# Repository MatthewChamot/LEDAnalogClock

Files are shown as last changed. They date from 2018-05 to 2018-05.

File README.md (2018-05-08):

# LEDAnalogClock
Project by Matthew Chamot

Code and CAD files for an analog LED clock.  

Sometimes in the middle of the night, it is hard to easily see the time.  This clock acts as a night light and is also easy to read, even if your eyes are still a little sleepy.  The angle of the clock hand shows the hours and the number of lit LEDs shows the minutes.   In the image below, the time is 10:45.

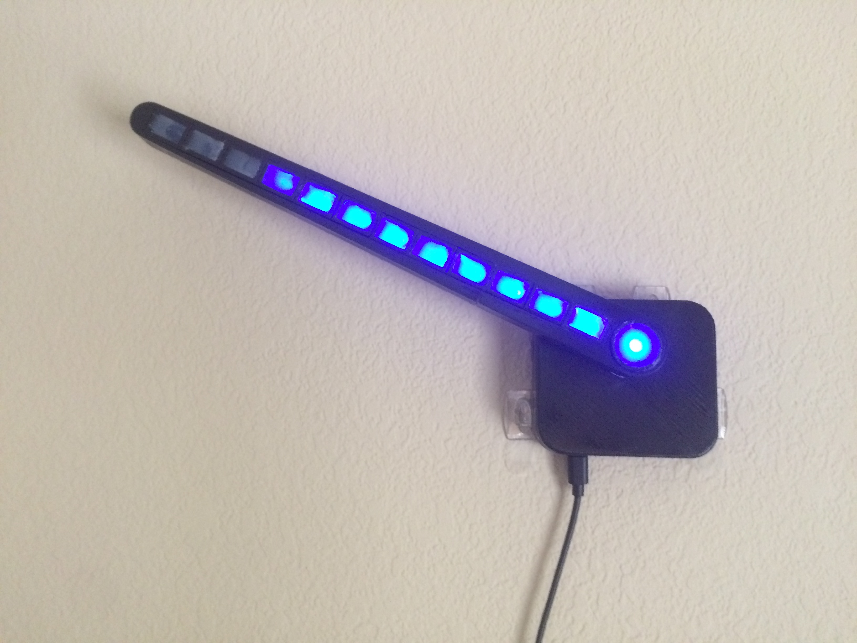
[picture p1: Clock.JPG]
clock image


#### Description
  The housing for the clock was custom designed and 3d printed to nicely enclose the electronics.  The microprocessor used was a Teensy 3.2 with the crystal attached for time accuracy.  The minutes are displayed by the number of LEDs lit along the arm.  One LED for every 5 minutes.  On every hour, the servo rotates the hand to the correct position and after 24 hours the servo rotates the hand in reverse for two full revolutions so that the wires inside do not get too twisted.  A unique worm gear design prevents the weight of the arm from back-driving the servo and allows the servo to be off until it is needed every hour.

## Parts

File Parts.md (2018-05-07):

## Parts Used

| Part | Quantity | Source |
| --- | :---: | --- |
| Diffused LED - Blue 10mm | 13 | https://www.sparkfun.com/products/10635  |
| Teensy 3.2 | 1 | https://www.sparkfun.com/products/13736  |
| Crystal 32kHz | 1 | https://www.sparkfun.com/products/540 |
| Rotary Encoder | 1 | https://www.sparkfun.com/products/9117 |
| Continous Rotation Micro Servo | 1 | https://www.sparkfun.com/products/10189  |
| Ribbon Cable - 6 wire | 1 | https://www.sparkfun.com/products/10646  |

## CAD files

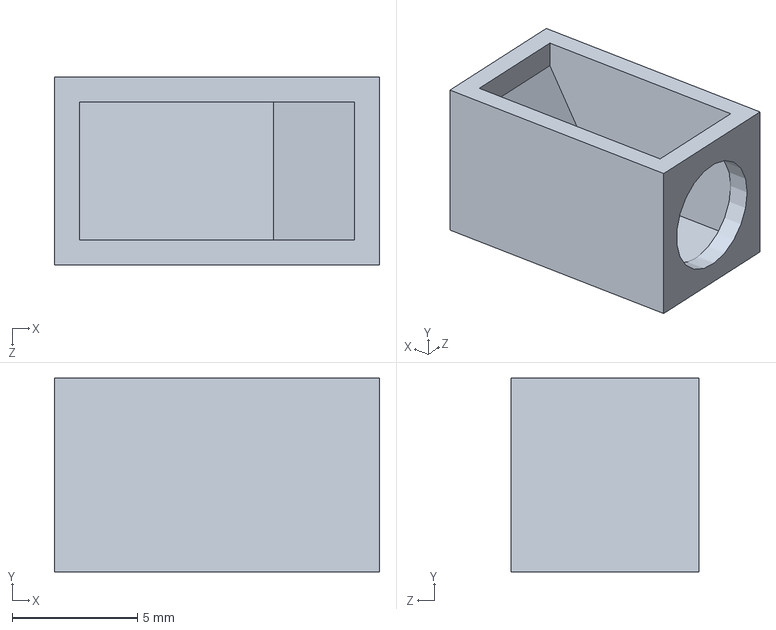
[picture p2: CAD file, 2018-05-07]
Clock CAD/Light_Test2.SLDPRT
13.0 x 7.75 x 7.50 mm

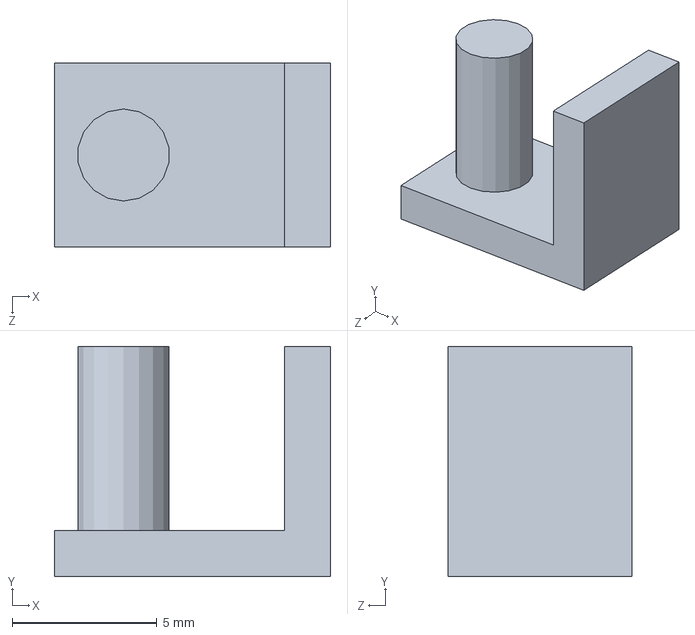
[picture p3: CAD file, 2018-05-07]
Clock CAD/Clip.SLDPRT
9.53 x 7.94 x 6.35 mm

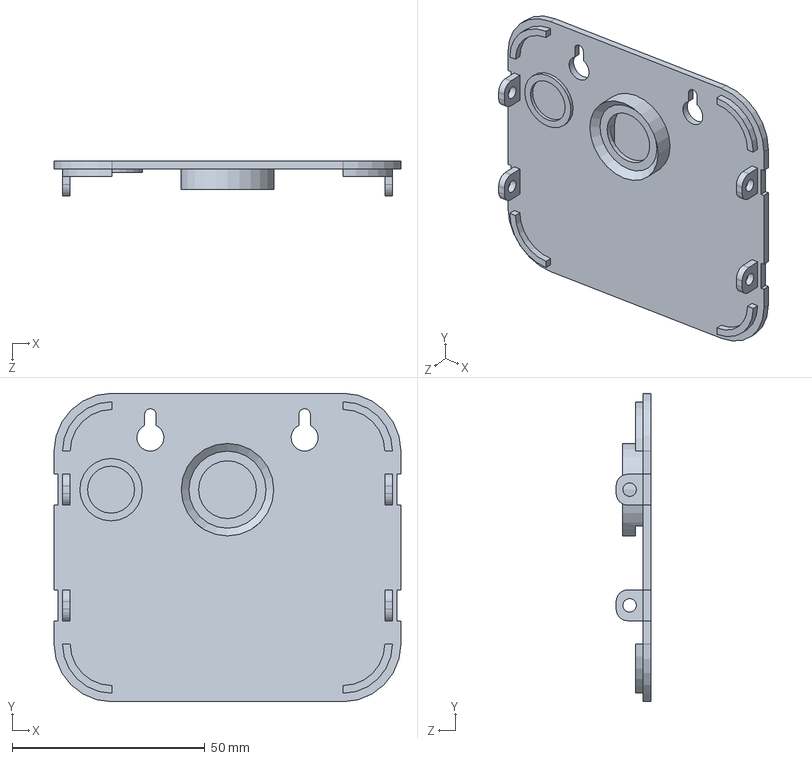
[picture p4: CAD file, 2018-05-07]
Clock CAD/Back.SLDPRT
90.0 x 80.0 x 9.00 mm

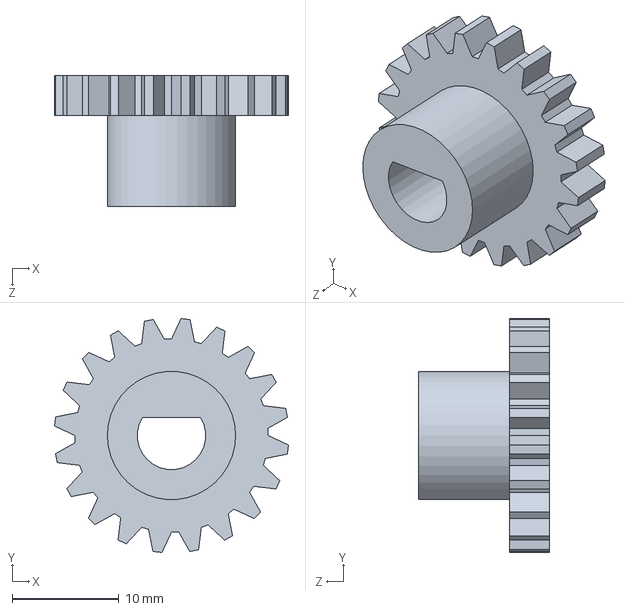
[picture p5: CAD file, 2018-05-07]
Clock CAD/20TGear.SLDPRT
21.9 x 21.9 x 12.2 mm

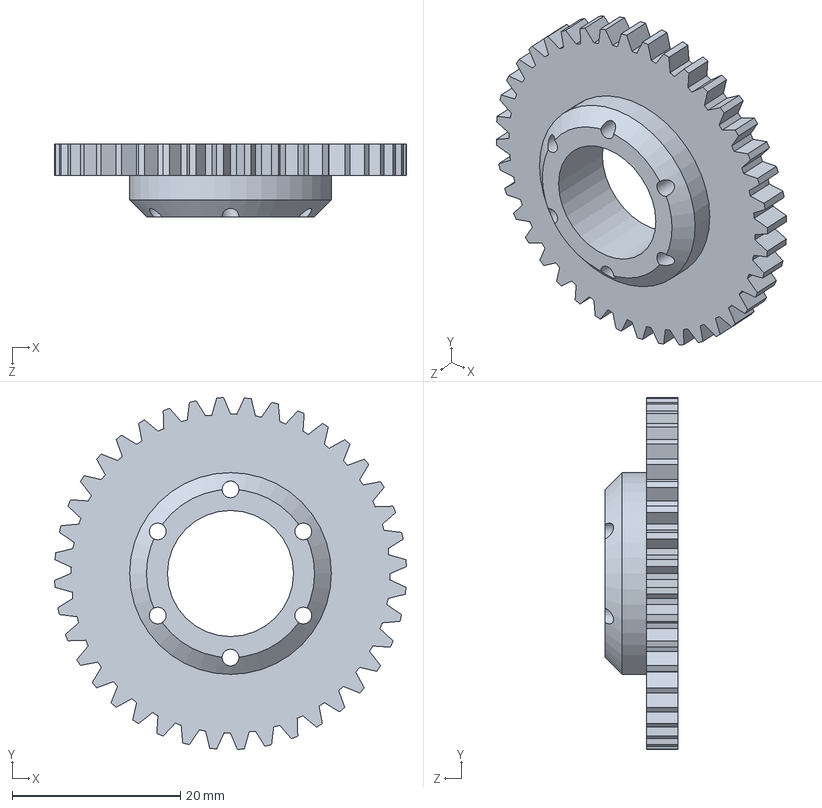
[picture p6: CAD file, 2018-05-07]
Clock CAD/40TGear.SLDPRT
41.9 x 41.9 x 8.65 mm

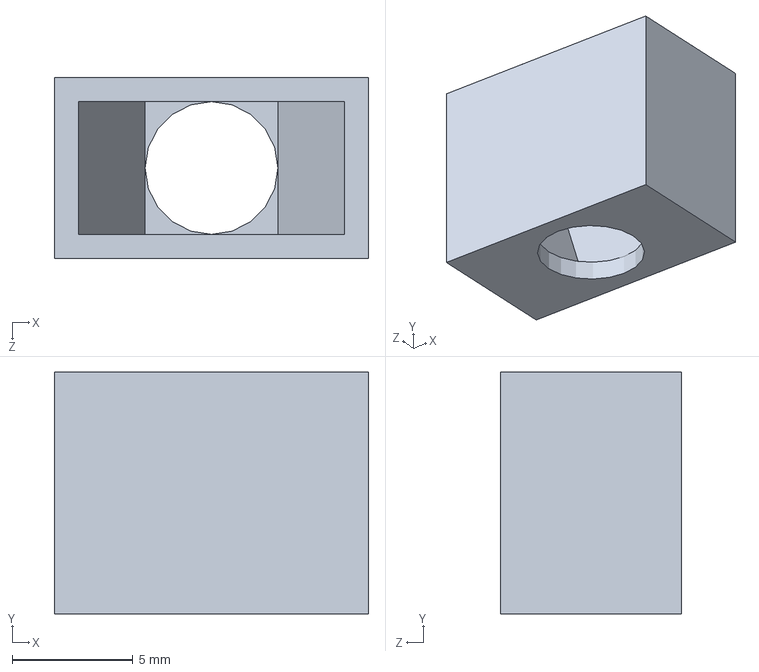
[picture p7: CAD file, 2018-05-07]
Clock CAD/Light_Test.SLDPRT
13.0 x 10.0 x 7.50 mm

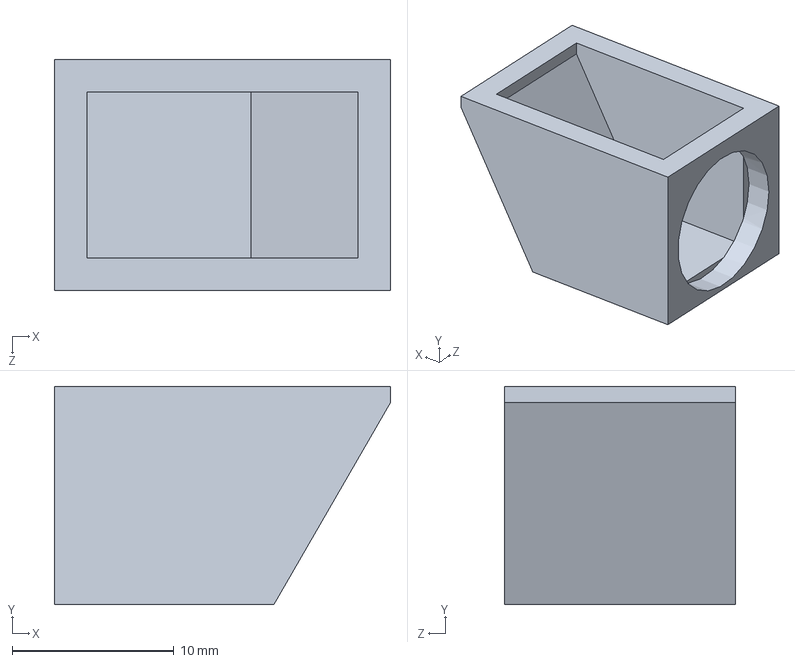
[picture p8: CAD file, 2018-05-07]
Clock CAD/Hand.SLDPRT
20.8 x 13.5 x 14.3 mm

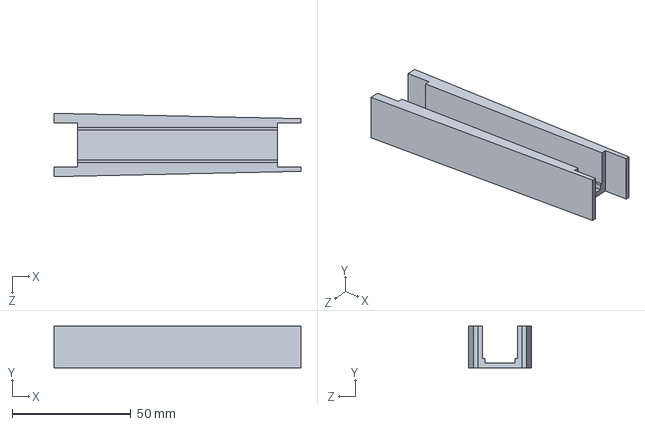
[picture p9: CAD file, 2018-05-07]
Clock CAD/Arm2.SLDPRT
103.8 x 17.5 x 26.6 mm

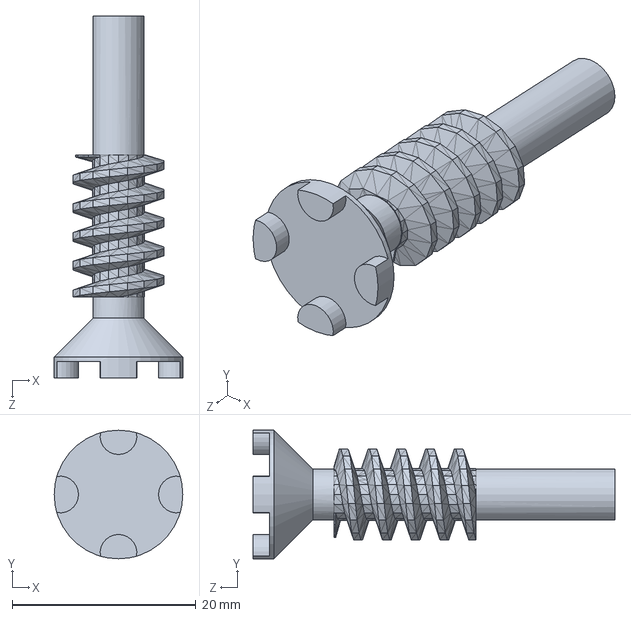
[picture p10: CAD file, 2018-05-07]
Clock CAD/WormGear.SLDPRT
14.0 x 14.0 x 39.4 mm

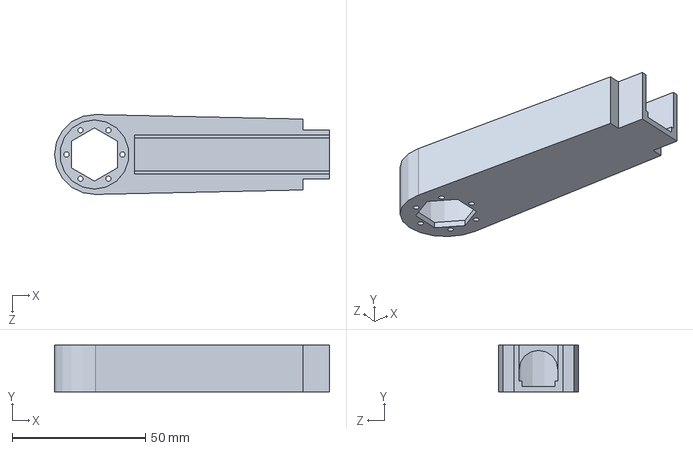
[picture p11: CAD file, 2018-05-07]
Clock CAD/Arm.SLDPRT
103.3 x 17.5 x 30.0 mm

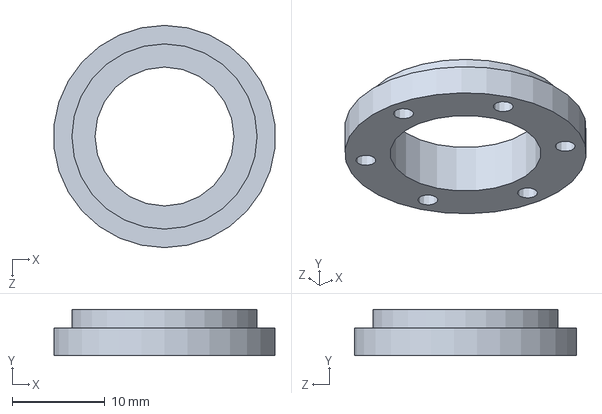
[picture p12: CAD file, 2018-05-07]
Clock CAD/GearHolder.SLDPRT
23.9 x 5.00 x 24.0 mm

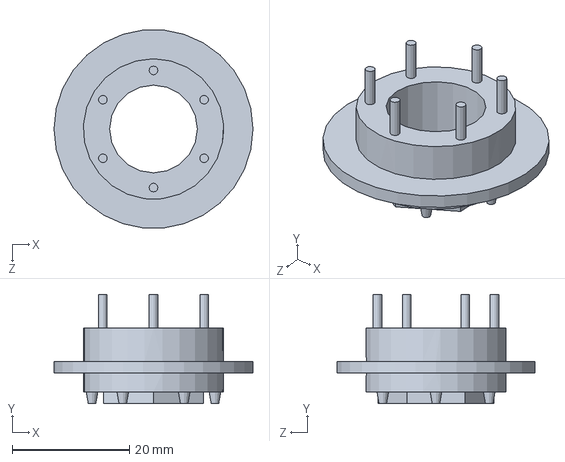
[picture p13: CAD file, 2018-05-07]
Clock CAD/Hub.SLDPRT
34.0 x 18.6 x 33.8 mm

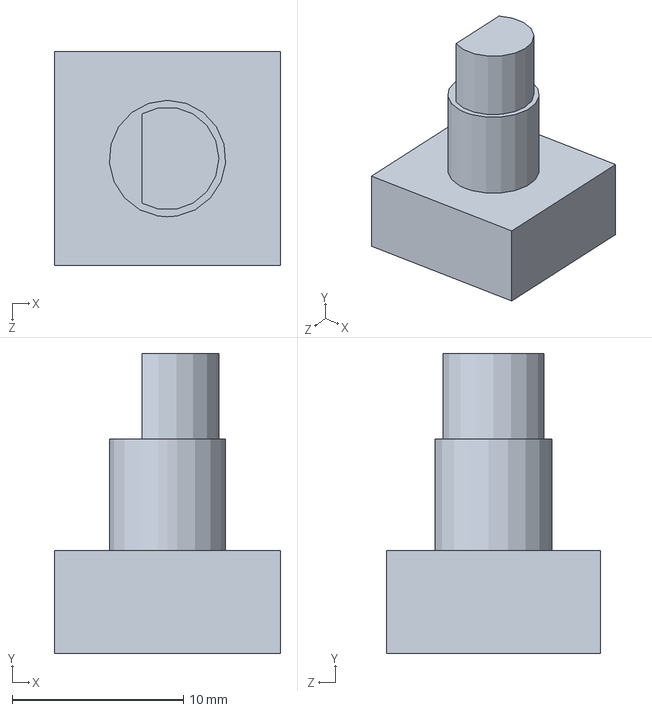
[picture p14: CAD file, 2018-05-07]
Clock CAD/Encoder.SLDPRT
13.2 x 17.5 x 12.5 mm

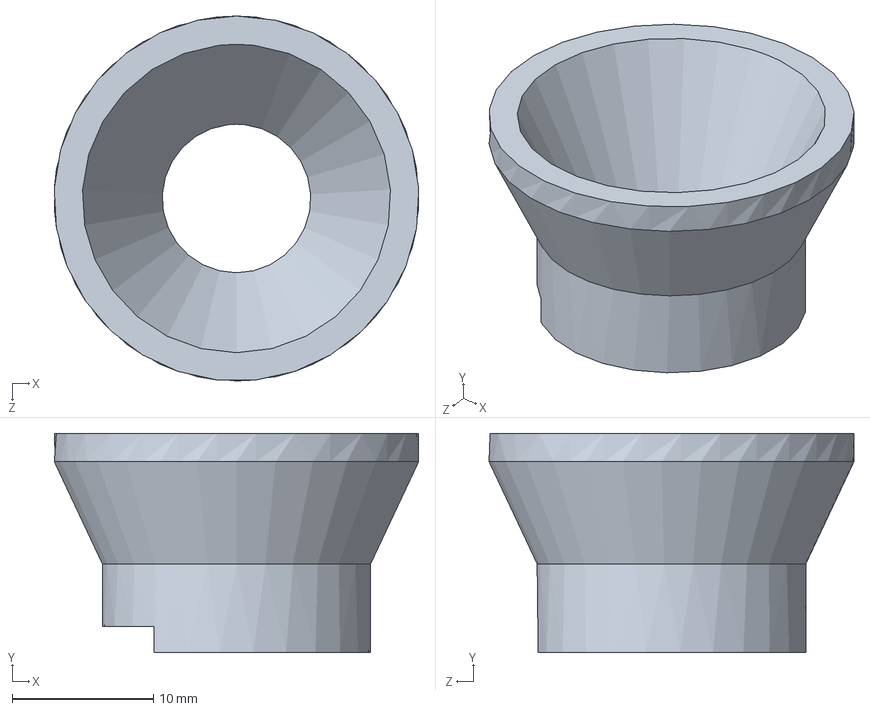
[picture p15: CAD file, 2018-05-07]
Clock CAD/Center Light.SLDPRT
25.8 x 15.5 x 25.8 mm

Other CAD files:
Clock CAD/LED.SLDPRT
Clock CAD/Peg.SLDPRT
Clock CAD/Light.SLDPRT
Clock CAD/20TGear.STL
Clock CAD/40TGear.STL
Clock CAD/Arm.STL
Clock CAD/Arm2.STL
Clock CAD/Arm3.SLDPRT
Clock CAD/Arm3.STL
Clock CAD/Back.STL
Clock CAD/Body.SLDPRT
Clock CAD/Body.STL
Clock CAD/Center Light.STL
Clock CAD/Clip.STL
Clock CAD/Hand.STL
Clock CAD/Hub.STL
Clock CAD/Light_Test.STL
Clock CAD/Light_Test2.STL
Clock CAD/Micro Servo.SLDPRT
Clock CAD/Peg.STL
Clock CAD/QuadHorn.SLDPRT
Clock CAD/Teensy32.SLDPRT
Clock CAD/Test.STL
Clock CAD/Washer.SLDPRT
Clock CAD/Washer.STL
Clock CAD/WormGear.STL

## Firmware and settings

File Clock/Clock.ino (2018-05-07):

//  Clock Code  
//  Created by Matthew Chamot 
//  March 2018

// Encoder Variables
#define ENC_A 7
#define ENC_B 8
#define CW 0
#define CCW 180
#define STOP 89
volatile byte state = 0;
volatile byte count = 0;
volatile byte dir = CCW;  // direction
volatile byte ledcount = 0;

// Variable keep track of state and timing
bool reset_mode = true;
bool button_pushed = false;
bool setting_time = false;
int pos = 0;
unsigned long hold_time = 0;

// Timer for PWM for the center LED
IntervalTimer ledTimer;

// Servo Variables
#include <Servo.h>
Servo motor;

// Time Variables
#include <TimeLib.h>

// LED Variables
#define LEDC  12
#define LED1  9 //3
#define LED2  6 //4
#define LED3  4 //5
#define LED4  23 //6
#define LED5  20 //9
#define LED6  32 //10
#define LED7  10 //23
#define LED8  5 //22
#define LED9  3 //21
#define LED10 22 //20
#define LED11 21 //25
#define LED12 25 //32


void setup() {
  
  // Encoder
  pinMode(ENC_A, INPUT);
  digitalWrite(ENC_A, HIGH);
  pinMode(ENC_B, INPUT);
  digitalWrite(ENC_B, HIGH);
  attachInterrupt(digitalPinToInterrupt(ENC_A), A_ISR, CHANGE);
  attachInterrupt(digitalPinToInterrupt(ENC_B), B_ISR, CHANGE);
  Serial.begin (115200);
  Serial.println("Start");
  ledTimer.begin(centerPWM,1000);  // every .001 seconds 

  // Servo
  motor.attach(1);
  motor.write(STOP);

  // Time
  // set the Time library to use Teensy 3.0's RTC to keep time
  setSyncProvider(getTeensy3Time);

  // LED test on startup
  int LedTime = 100;
  pinMode(LED1, OUTPUT);
  pinMode(LED2, OUTPUT);
  pinMode(LED3, OUTPUT);
  pinMode(LED4, OUTPUT);
  pinMode(LED5, OUTPUT);
  pinMode(LED6, OUTPUT);
  pinMode(LED7, OUTPUT);
  pinMode(LED8, OUTPUT);
  pinMode(LED9, OUTPUT);
  pinMode(LED10, OUTPUT);
  pinMode(LED11, OUTPUT);
  pinMode(LED12, OUTPUT);
  pinMode(LEDC, OUTPUT);
  digitalWrite(LEDC, HIGH);
  delay(LedTime);
  analogWrite(LED1, 127);
  delay(LedTime);
  analogWrite(LED2, 127);
  delay(LedTime);
  analogWrite(LED3, 127);
  delay(LedTime);
  analogWrite(LED4, 127);
  delay(LedTime);
  analogWrite(LED5, 127);
  delay(LedTime);
  analogWrite(LED6, 127);
  delay(LedTime);
  analogWrite(LED7, 127);
  delay(LedTime);
  analogWrite(LED8, 127);
  delay(LedTime);
  analogWrite(LED9, 127);
  delay(LedTime);
  analogWrite(LED10, 127);
  delay(LedTime);
  analogWrite(LED11, 127);
  delay(LedTime);
  analogWrite(LED12, 127);
  delay(LedTime);
  analogWrite(LED12, 0);
  delay(LedTime);
  analogWrite(LED11, 0);
  delay(LedTime);
  analogWrite(LED10, 0);
  delay(LedTime);
  analogWrite(LED9, 0);
  delay(LedTime);
  analogWrite(LED8, 0);
  delay(LedTime);
  analogWrite(LED7, 0);
  delay(LedTime);
  analogWrite(LED6, 0);
  delay(LedTime);
  analogWrite(LED5, 0);
  delay(LedTime);
  analogWrite(LED4, 0);
  delay(LedTime);
  analogWrite(LED3, 0);
  delay(LedTime);
  analogWrite(LED2, 0);
  delay(LedTime);
  analogWrite(LED1, 0);
  
  // Button
  pinMode(14,INPUT_PULLUP);
  attachInterrupt(digitalPinToInterrupt(14), buttonpress, FALLING);

    
  // Reseting Mode
  while(reset_mode) {
    if(button_pushed == true) {
      delay(1000);
      if(digitalRead(14)==LOW) {
        reset_mode = false;
        Serial.println("Exiting Setup");
      }
      else {
        motor.write(CCW);
        Serial.println("Going Back");
      }
      button_pushed = false;
    }
    // Move back an half hour
    if(count<=255 && count>50) {
      motor.write(STOP);
      count = 0;
    }
  }

  // Initial Movement
  setting_time = true;
  pos = hour();
  if(pos < 12) {
    pos = pos + 12;
  }
  else {
    pos = pos - 12;
  }
  pos = pos*2;
  dir = CW;
  lightleds();
  motor.write(dir);

  while(setting_time) {
    if(count==pos) {
      motor.write(STOP);
      lightleds();
      setting_time = false;
    }
  }
  
}

void loop() {
    
  // Read the hour from the RTC and convert to encoder position
  pos = hour();
  if(pos < 12) {
    pos = pos + 12;
  }
  else {
    pos = pos - 12;
  }
  pos = pos*2;

  // Every 24 hours the clock fully reverses to prevent twisting of the LED wiring.
  if(count == 46 && pos == 0) {
    dir = CCW;
    motor.attach(1);
    motor.write(dir);
    setting_time  = true;
    while(setting_time) {
      if(count == 0) {
        motor.write(STOP);
        motor.detach();
        setting_time = false;
      }
      if(count > 200) {
        error();
      }
    }
    dir = CW;
    analogWrite(LED12, 0);
    analogWrite(LED11, 0);
    analogWrite(LED10, 0);
    analogWrite(LED9, 0);
    analogWrite(LED8, 0);
    analogWrite(LED7, 0);
    analogWrite(LED6, 0);
    analogWrite(LED5, 0);
    analogWrite(LED4, 0);
    analogWrite(LED3, 0);
    analogWrite(LED2, 0);
    analogWrite(LED1, 0);
  }

  // Every hour the clock hand moves 1/12 of a full circle
  if(count < pos) {
    motor.attach(1);
    motor.write(60);
    setting_time = true;
    while(setting_time) {
      if(count==pos) {
        motor.write(STOP);
        motor.detach();
        setting_time = false;
      }
    }  
  }
  
  // If the clock hand has rotated more than 2 revolutions, something is wrong
  if(count > 46) {
    error();
  }

  // Check the time every 10 seconds and light the LEDs to display minutes
  Serial.println(count);
  lightleds();
  delay(10000);

}



// ISR for encoder, switch A
// Encoder alternates ABAB for one direction and BABA for the other.
void A_ISR() {
  Serial.print("A ");
  if (dir == CW)
  {
    if (state == 1) state = 2;
    if (state == 3)
    {
      state = 0;
      count++;  
    }
  }

  else if (dir == CCW)
  {
    if (state == 0) state = 1;
    if (state == 2) state = 3;
  }
}

// ISR for encoder, switch B
void B_ISR() {
  Serial.print("B ");
  if (dir == CW)
  {
    if (state == 0) state = 1;
    if (state == 2) state = 3;
  }

  else if (dir == CCW)
  {
    if(state == 1) state = 2;
    if (state == 3)
    {
      state = 0;
      count--;  
    }
  }
}

// Reset button
void buttonpress() {
  //motor.write(STOP);
  button_pushed = true;
}

// Real Time Clock functionality
time_t getTeensy3Time()
{
  return Teensy3Clock.get();
}


// Light the LEDs to display the number of minutes past the hour
void lightleds() {
  int m = minute();
  int maxPWM = 32;
  int value;
  if(m%5 == 4)
    value = maxPWM/2;
  else if(m%5 == 3)
    value = maxPWM/4;
  else if(m%5 == 2)
    value = maxPWM/8;
  else if(m%5 == 1)
    value = maxPWM/16;
  else
    value = 0;
     

  
  if(m>=1 && m <= 4)
    analogWrite(LED1, value*.8);
  else if(m>=5 && m <= 9) {
    analogWrite(LED1, maxPWM*.8);
    analogWrite(LED2, value);
  }
  else if(m>=10 && m <= 14) {
    analogWrite(LED1, maxPWM*.8);
    analogWrite(LED2, maxPWM);
    analogWrite(LED3, value);
  }
  else if(m>=15 && m <= 19) {
    analogWrite(LED1, maxPWM*.8);
    analogWrite(LED2, maxPWM);
    analogWrite(LED3, maxPWM);
    analogWrite(LED4, value);
  }
  else if(m>=20 && m <= 24) {
    analogWrite(LED1, maxPWM*.8);
    analogWrite(LED2, maxPWM);
    analogWrite(LED3, maxPWM);
    analogWrite(LED4, maxPWM);
    analogWrite(LED5, value);
  }
   
  else if(m>=25 && m <= 29) {
    analogWrite(LED1, maxPWM*.8);
    analogWrite(LED2, maxPWM);
    analogWrite(LED3, maxPWM);
    analogWrite(LED4, maxPWM);
    analogWrite(LED5, maxPWM);
    analogWrite(LED6, value*.6);
  }
  else if(m>=30 && m <= 34) {
    analogWrite(LED1, maxPWM*.8);
    analogWrite(LED2, maxPWM);
    analogWrite(LED3, maxPWM);
    analogWrite(LED4, maxPWM);
    analogWrite(LED5, maxPWM);
    analogWrite(LED6, maxPWM*.6);
    analogWrite(LED7, value*.8);
  }
  else if(m>=35 && m <= 39) {
    analogWrite(LED1, maxPWM*.8);
    analogWrite(LED2, maxPWM);
    analogWrite(LED3, maxPWM);
    analogWrite(LED4, maxPWM);
    analogWrite(LED5, maxPWM);
    analogWrite(LED6, maxPWM*.6);
    analogWrite(LED7, maxPWM*.8);
    analogWrite(LED8, value*.8);
  }
  else if(m>=40 && m <= 44) {
    analogWrite(LED1, maxPWM*.8);
    analogWrite(LED2, maxPWM);
    analogWrite(LED3, maxPWM);
    analogWrite(LED4, maxPWM);
    analogWrite(LED5, maxPWM);
    analogWrite(LED6, maxPWM*.6);
    analogWrite(LED7, maxPWM*.8);
    analogWrite(LED8, maxPWM*.8);
    analogWrite(LED9, value*.8);
  }
  else if(m>=45 && m <= 49) {
    analogWrite(LED1, maxPWM*.8);
    analogWrite(LED2, maxPWM);
    analogWrite(LED3, maxPWM);
    analogWrite(LED4, maxPWM);
    analogWrite(LED5, maxPWM);
    analogWrite(LED6, maxPWM*.6);
    analogWrite(LED7, maxPWM*.8);
    analogWrite(LED8, maxPWM*.8);
    analogWrite(LED9, maxPWM*.8);
    analogWrite(LED10, value*.8);
  }
  else if(m>=50 && m <= 54) {
    analogWrite(LED1, maxPWM*.8);
    analogWrite(LED2, maxPWM);
    analogWrite(LED3, maxPWM);
    analogWrite(LED4, maxPWM);
    analogWrite(LED5, maxPWM);
    analogWrite(LED6, maxPWM*.6);
    analogWrite(LED7, maxPWM*.8);
    analogWrite(LED8, maxPWM*.8);
    analogWrite(LED9, maxPWM*.8);
    analogWrite(LED10, maxPWM*.8);
    analogWrite(LED11, value*.8);
  }
  else if(m>=55 && m <= 59) {
    analogWrite(LED1, maxPWM*.8);
    analogWrite(LED2, maxPWM);
    analogWrite(LED3, maxPWM);
    analogWrite(LED4, maxPWM);
    analogWrite(LED5, maxPWM);
    analogWrite(LED6, maxPWM*.6);
    analogWrite(LED7, maxPWM*.8);
    analogWrite(LED8, maxPWM*.8);
    analogWrite(LED9, maxPWM*.8);
    analogWrite(LED10, maxPWM*.8);
    analogWrite(LED11, maxPWM*.8);
    analogWrite(LED12, value*.8);
  }
  else {
    analogWrite(LED1, 0);
    analogWrite(LED2, 0);
    analogWrite(LED3, 0);
    analogWrite(LED4, 0);
    analogWrite(LED5, 0);
    analogWrite(LED6, 0);
    analogWrite(LED7, 0);
    analogWrite(LED8, 0);
    analogWrite(LED9, 0);
    analogWrite(LED10, 0);
    analogWrite(LED11, 0);
    analogWrite(LED12, 0);
  }
}

// Ran out of PWM pins so center LED uses a seperate timer for PWM
void centerPWM() {
  if(ledcount < 4) {
    digitalWrite(LEDC, LOW);
    ledcount++;
  }
  else {
    digitalWrite(LEDC, HIGH);
    ledcount = 0;
  }
}


// If something fails everything should shut to prenvent the wires from becoming too twisted.
void error() {
  analogWrite(LED12, 0);
  analogWrite(LED11, 0);
  analogWrite(LED10, 0);
  analogWrite(LED9, 0);
  analogWrite(LED8, 0);
  analogWrite(LED7, 0);
  analogWrite(LED6, 0);
  analogWrite(LED5, 0);
  analogWrite(LED4, 0);
  analogWrite(LED3, 0);
  analogWrite(LED2, 0);
  analogWrite(LED1, 0);
  motor.detach();
  count = 0;
  while(true) {
    digitalWrite(LEDC, HIGH);
    delay(1000);
    digitalWrite(LEDC, LOW);
    delay(1000);
  }
}

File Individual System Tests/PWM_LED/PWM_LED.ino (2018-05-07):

/* LED Blink, Teensyduino Tutorial #1
   http://www.pjrc.com/teensy/tutorial.html
 
   This example code is in the public domain.
*/

// Teensy 2.0 has the LED on pin 11
// Teensy++ 2.0 has the LED on pin 6
// Teensy 3.x / Teensy LC have the LED on pin 13
const int ledPin = 10;

// the setup() method runs once, when the sketch starts

void setup() {
  // initialize the digital pin as an output.
  pinMode(ledPin, OUTPUT);
}

// the loop() methor runs over and over again,
// as long as the board has power

void loop() {
  analogWrite(ledPin, 255);   // set the LED on
  delay(1000);                  // wait for a second
  analogWrite(ledPin, 127);    // set the LED off
  delay(1000);                  // wait for a second
  analogWrite(ledPin, 63);    // set the LED off
  delay(1000);                  // wait for a second
  analogWrite(ledPin, 31);    // set the LED off
  delay(1000);                  // wait for a second
  analogWrite(ledPin, 15);    // set the LED off
  delay(1000);                  // wait for a second
  analogWrite(ledPin, 0);    // set the LED off
  delay(1000);                  // wait for a second
}

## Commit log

2018-05-07 Final Arduino code for the clock
2018-05-07 CAD files used to 3D print all parts of the clock
    [20TGear.SLDPRT, 20TGear.STL, 40TGear.SLDPRT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]
